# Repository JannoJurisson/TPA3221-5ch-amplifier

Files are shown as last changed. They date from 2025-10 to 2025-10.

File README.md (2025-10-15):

# TPA3221-5ch-amplifier
A D-class car amplifier based on TPA3221, replaces BOSE 294009 car amplifier PCB.

The amplifier uses a Push-pull SMPS with a SG3525 controller to boost 12V to 24V. Transformer is hand-made using non-gapped ferrite transformer core TDK E-50.
Similar E cores can be used as the transformer is fastened to the pcb using cable ties 

There a 5 channels:
Channel 1-4 -> speaker outputs (@ 4ohm speakers > ~4x60W)
Channel 5   -> subwoofer output (TPA3221 in PBTL operation, @ 4ohm woofer > ~100w)

TPA3221 5ch amp_top
TPA3221 5ch amp_bottom

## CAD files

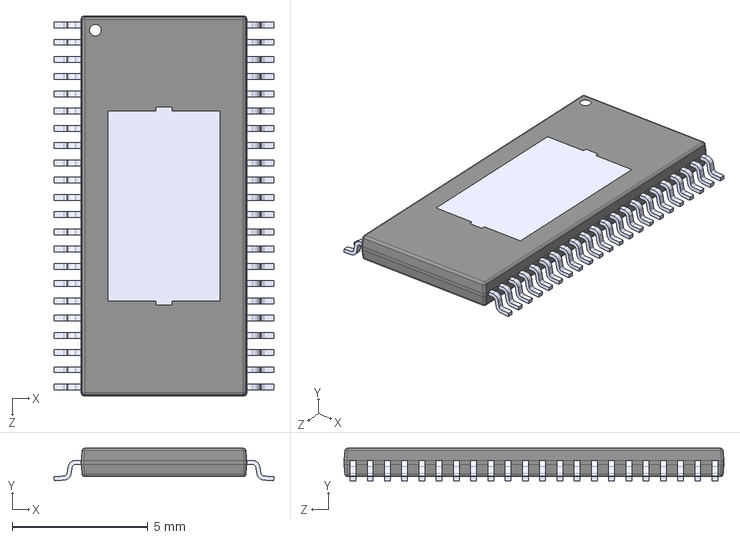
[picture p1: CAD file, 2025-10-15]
KiCAD/3d_models/TPA3221DDV.STEP
8.10 x 1.20 x 14.0 mm

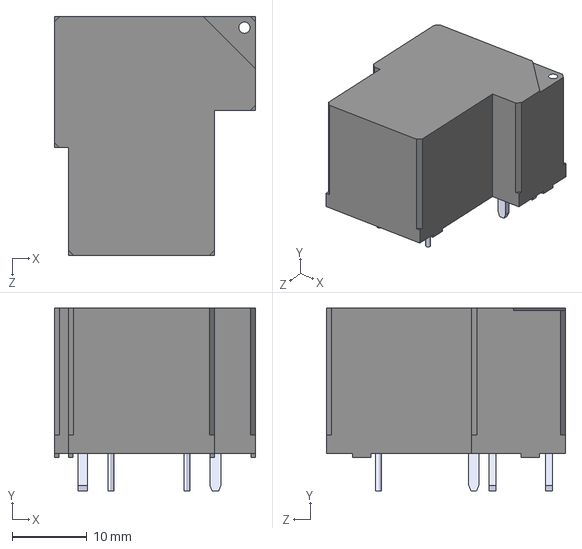
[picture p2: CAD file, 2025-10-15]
KiCAD/3d_models/GK-A-1A-12D-G.STEP
27.0 x 24.5 x 32.1 mm

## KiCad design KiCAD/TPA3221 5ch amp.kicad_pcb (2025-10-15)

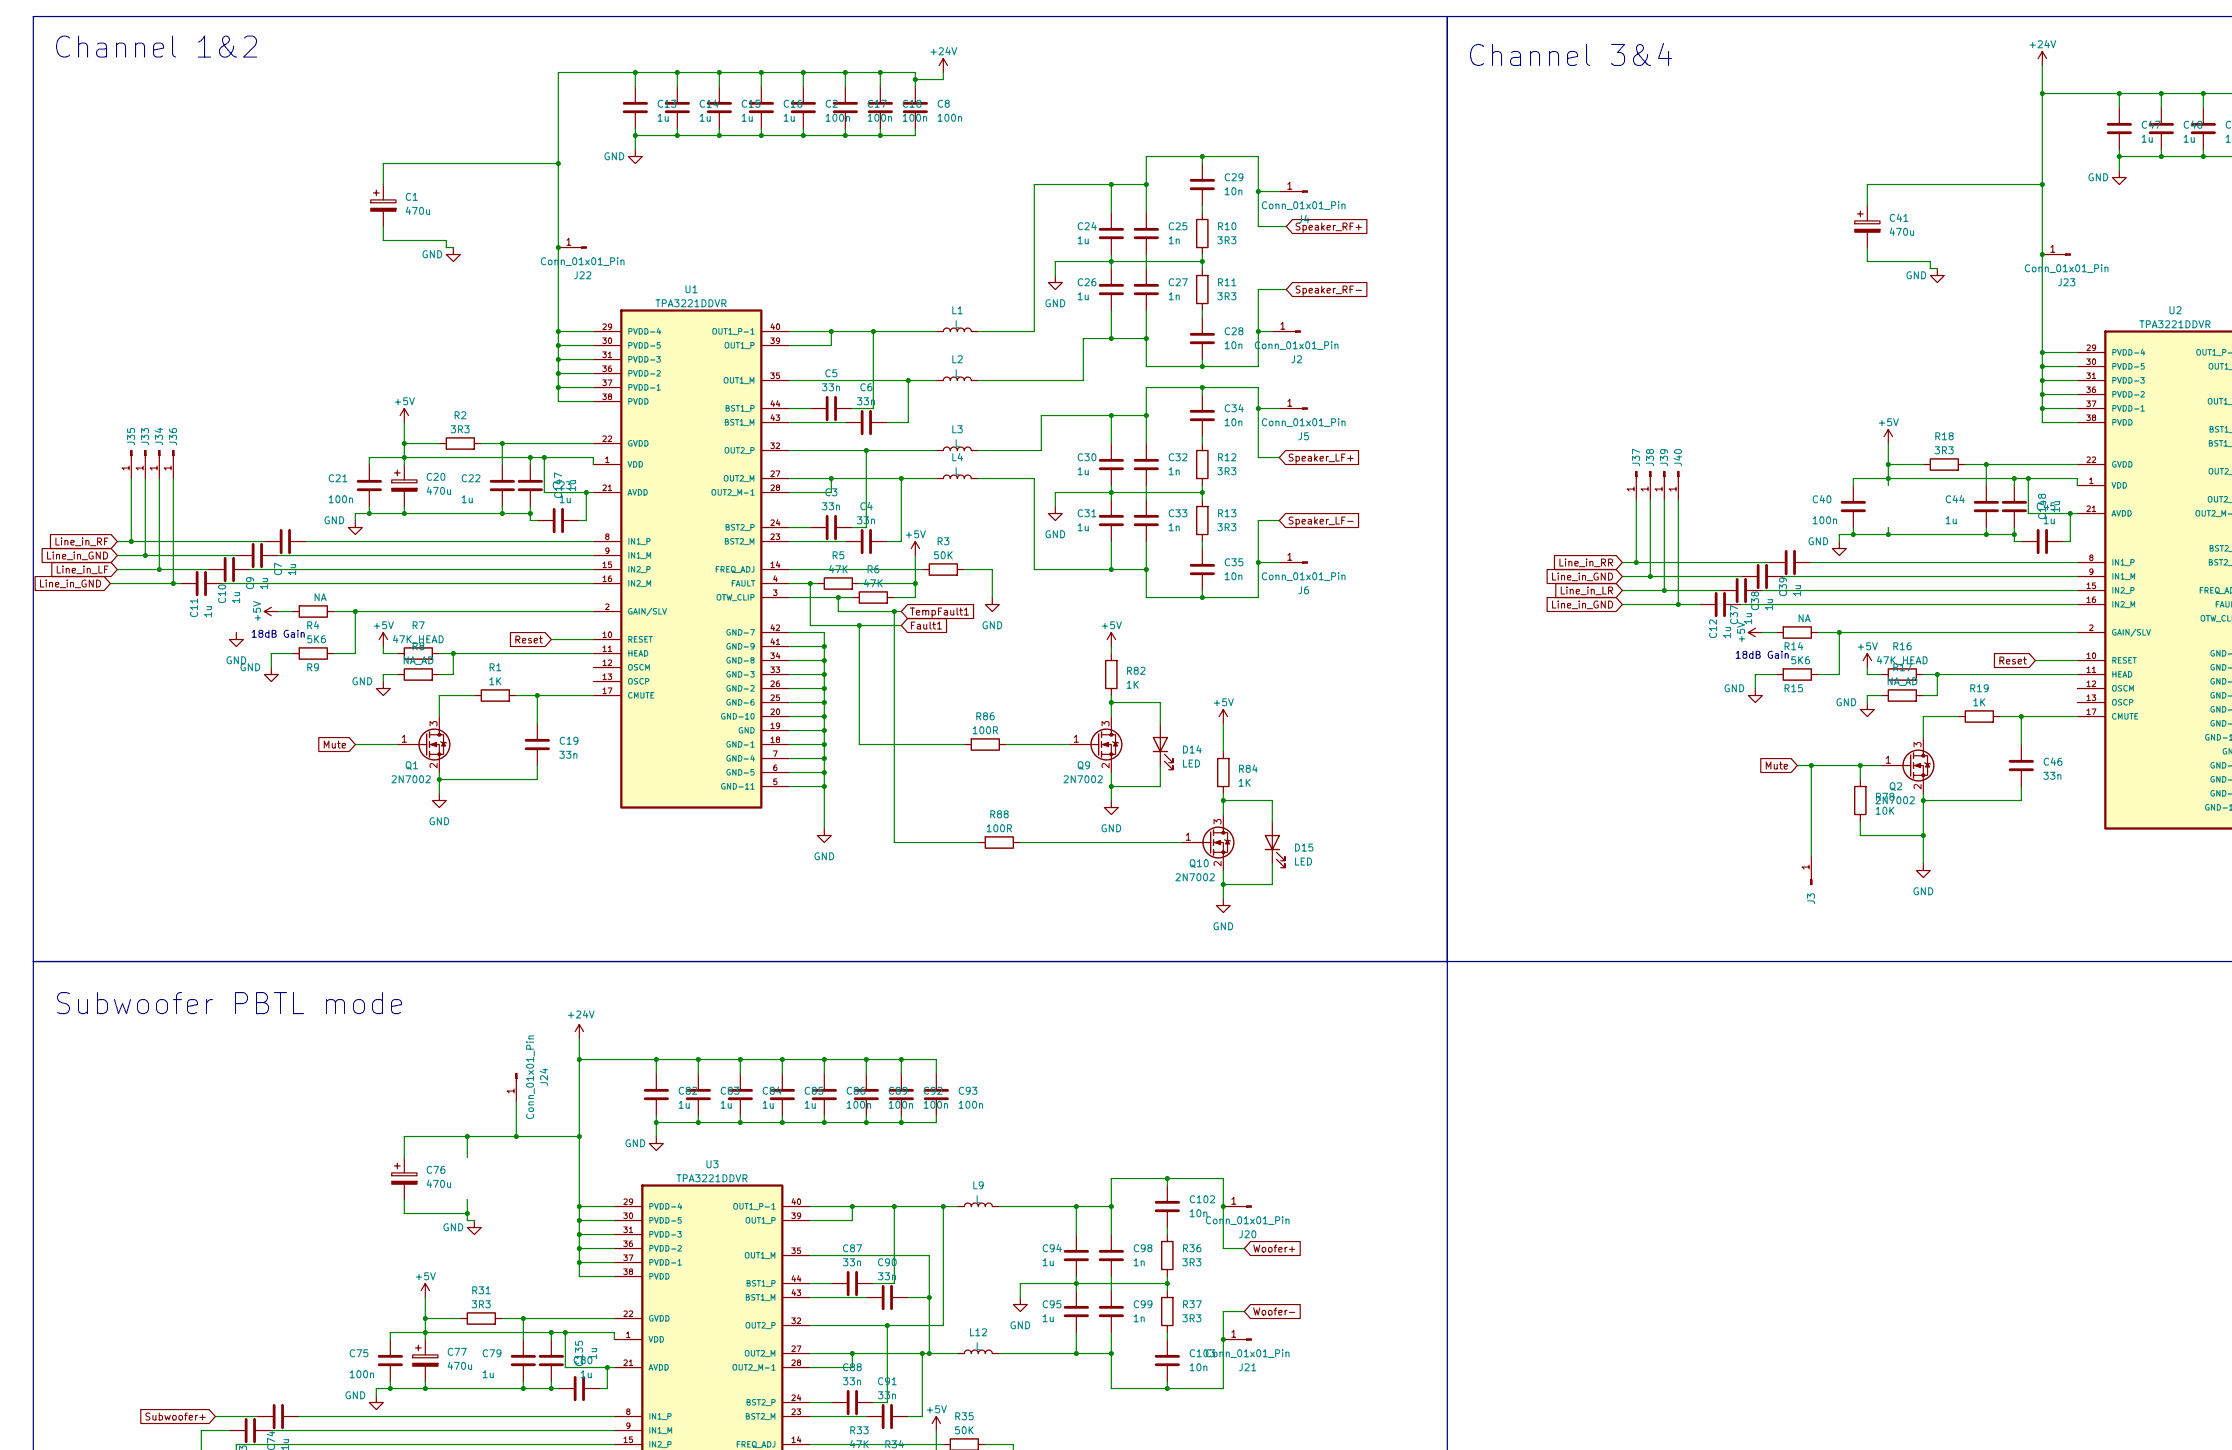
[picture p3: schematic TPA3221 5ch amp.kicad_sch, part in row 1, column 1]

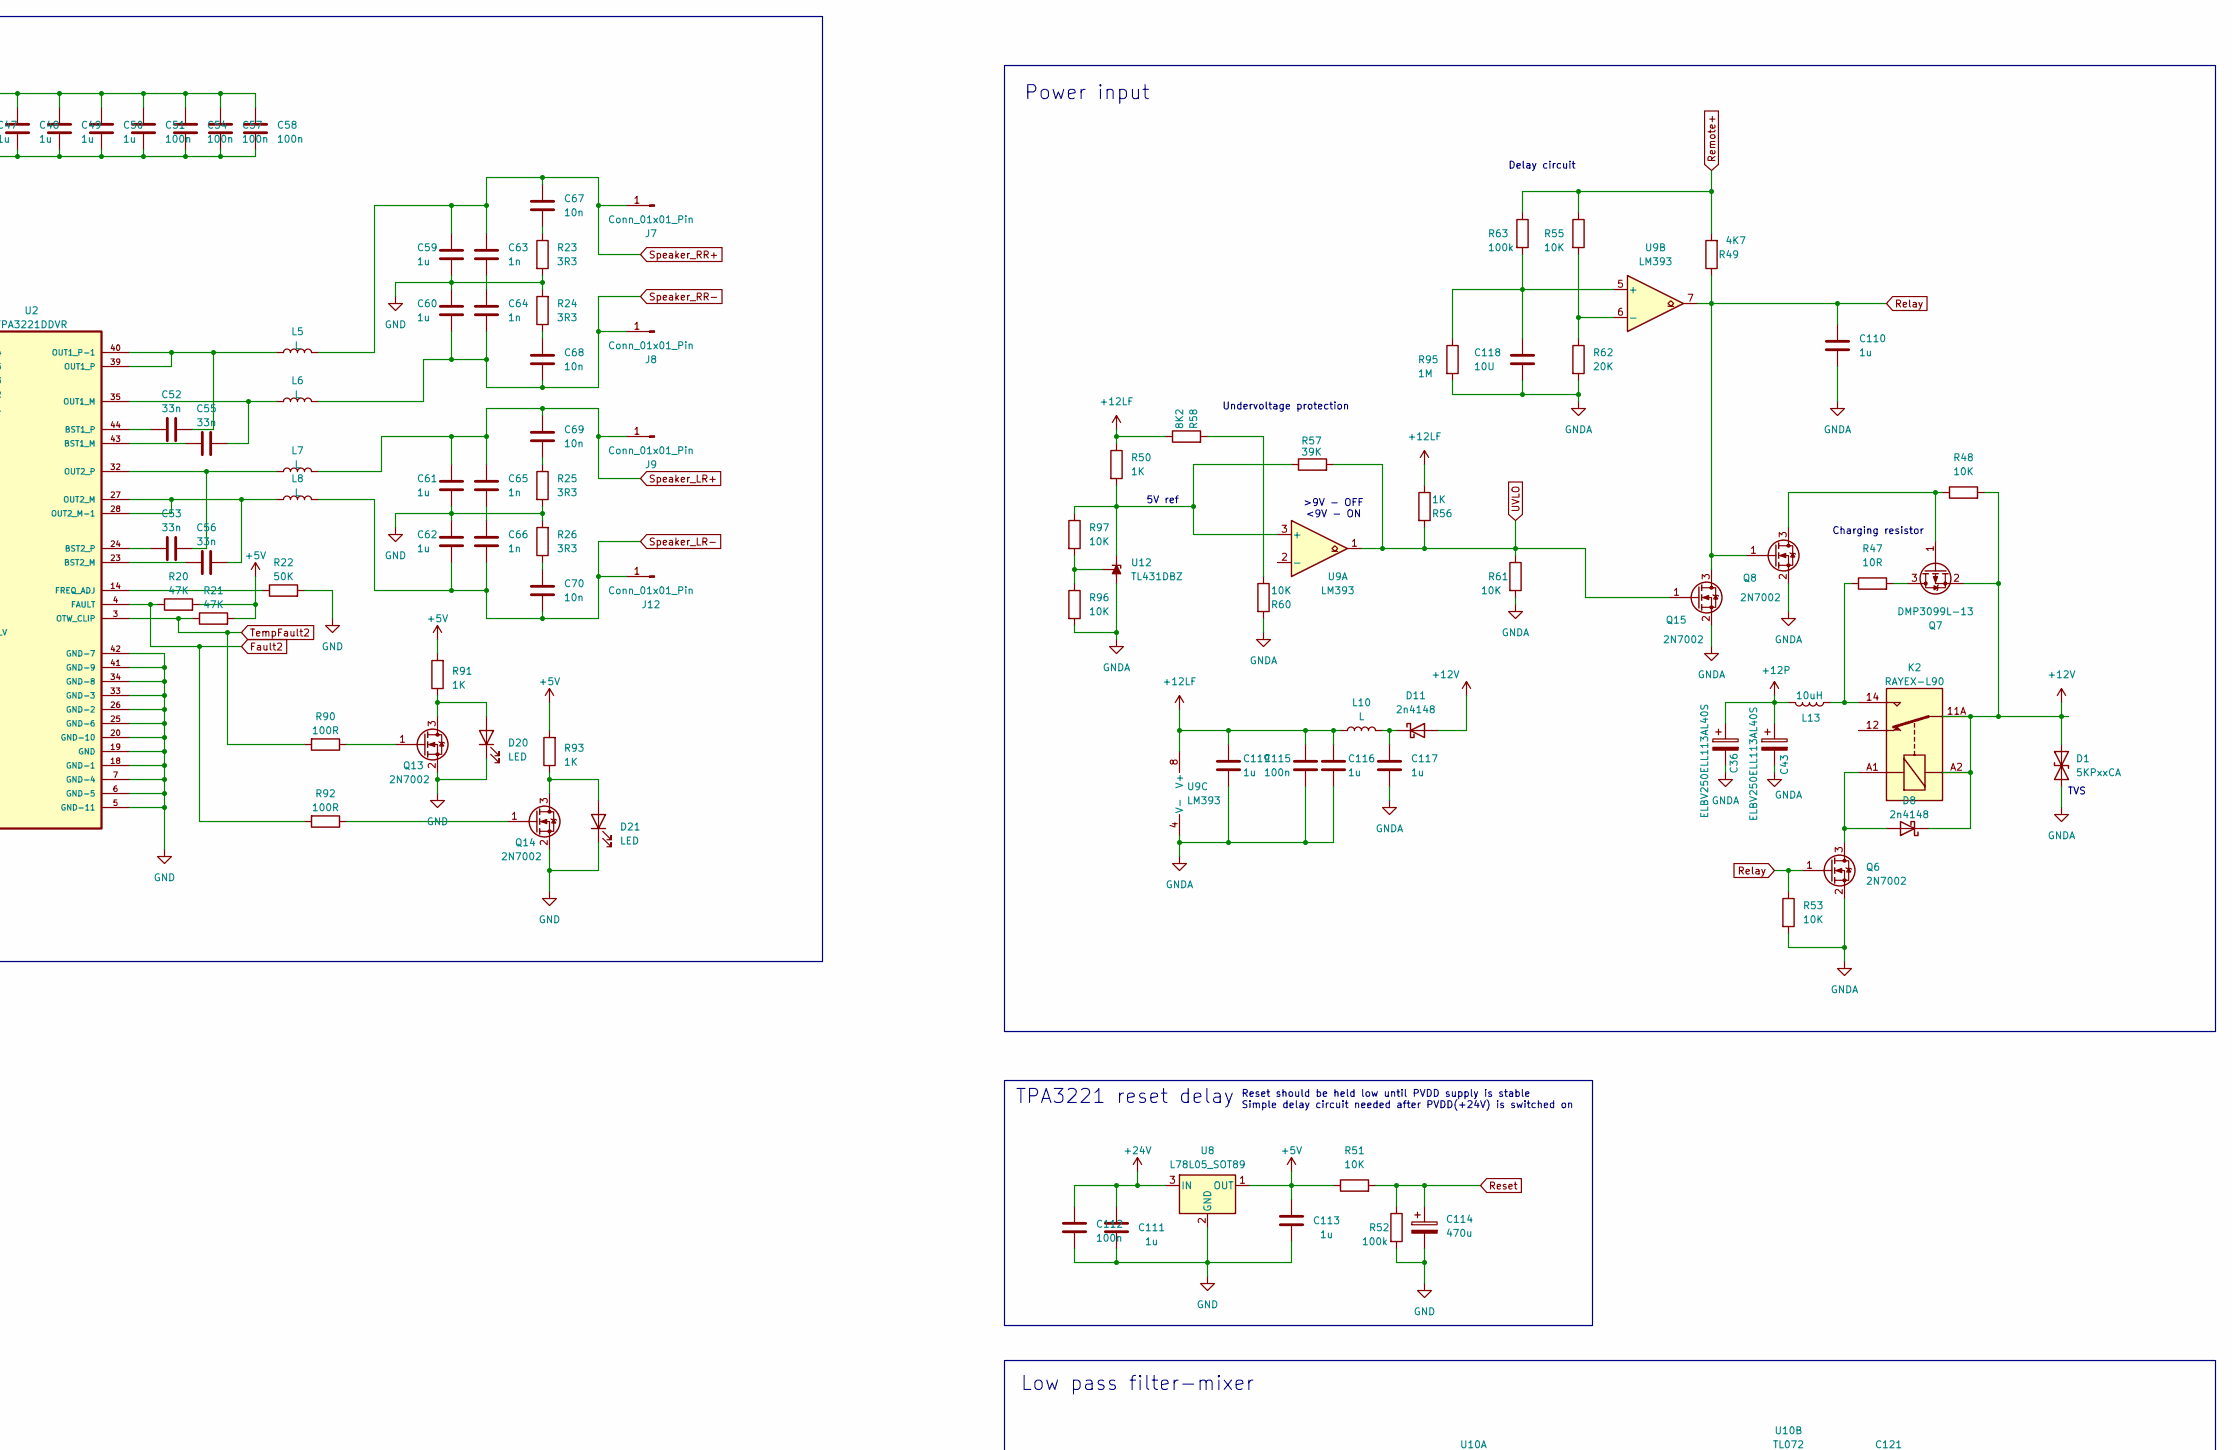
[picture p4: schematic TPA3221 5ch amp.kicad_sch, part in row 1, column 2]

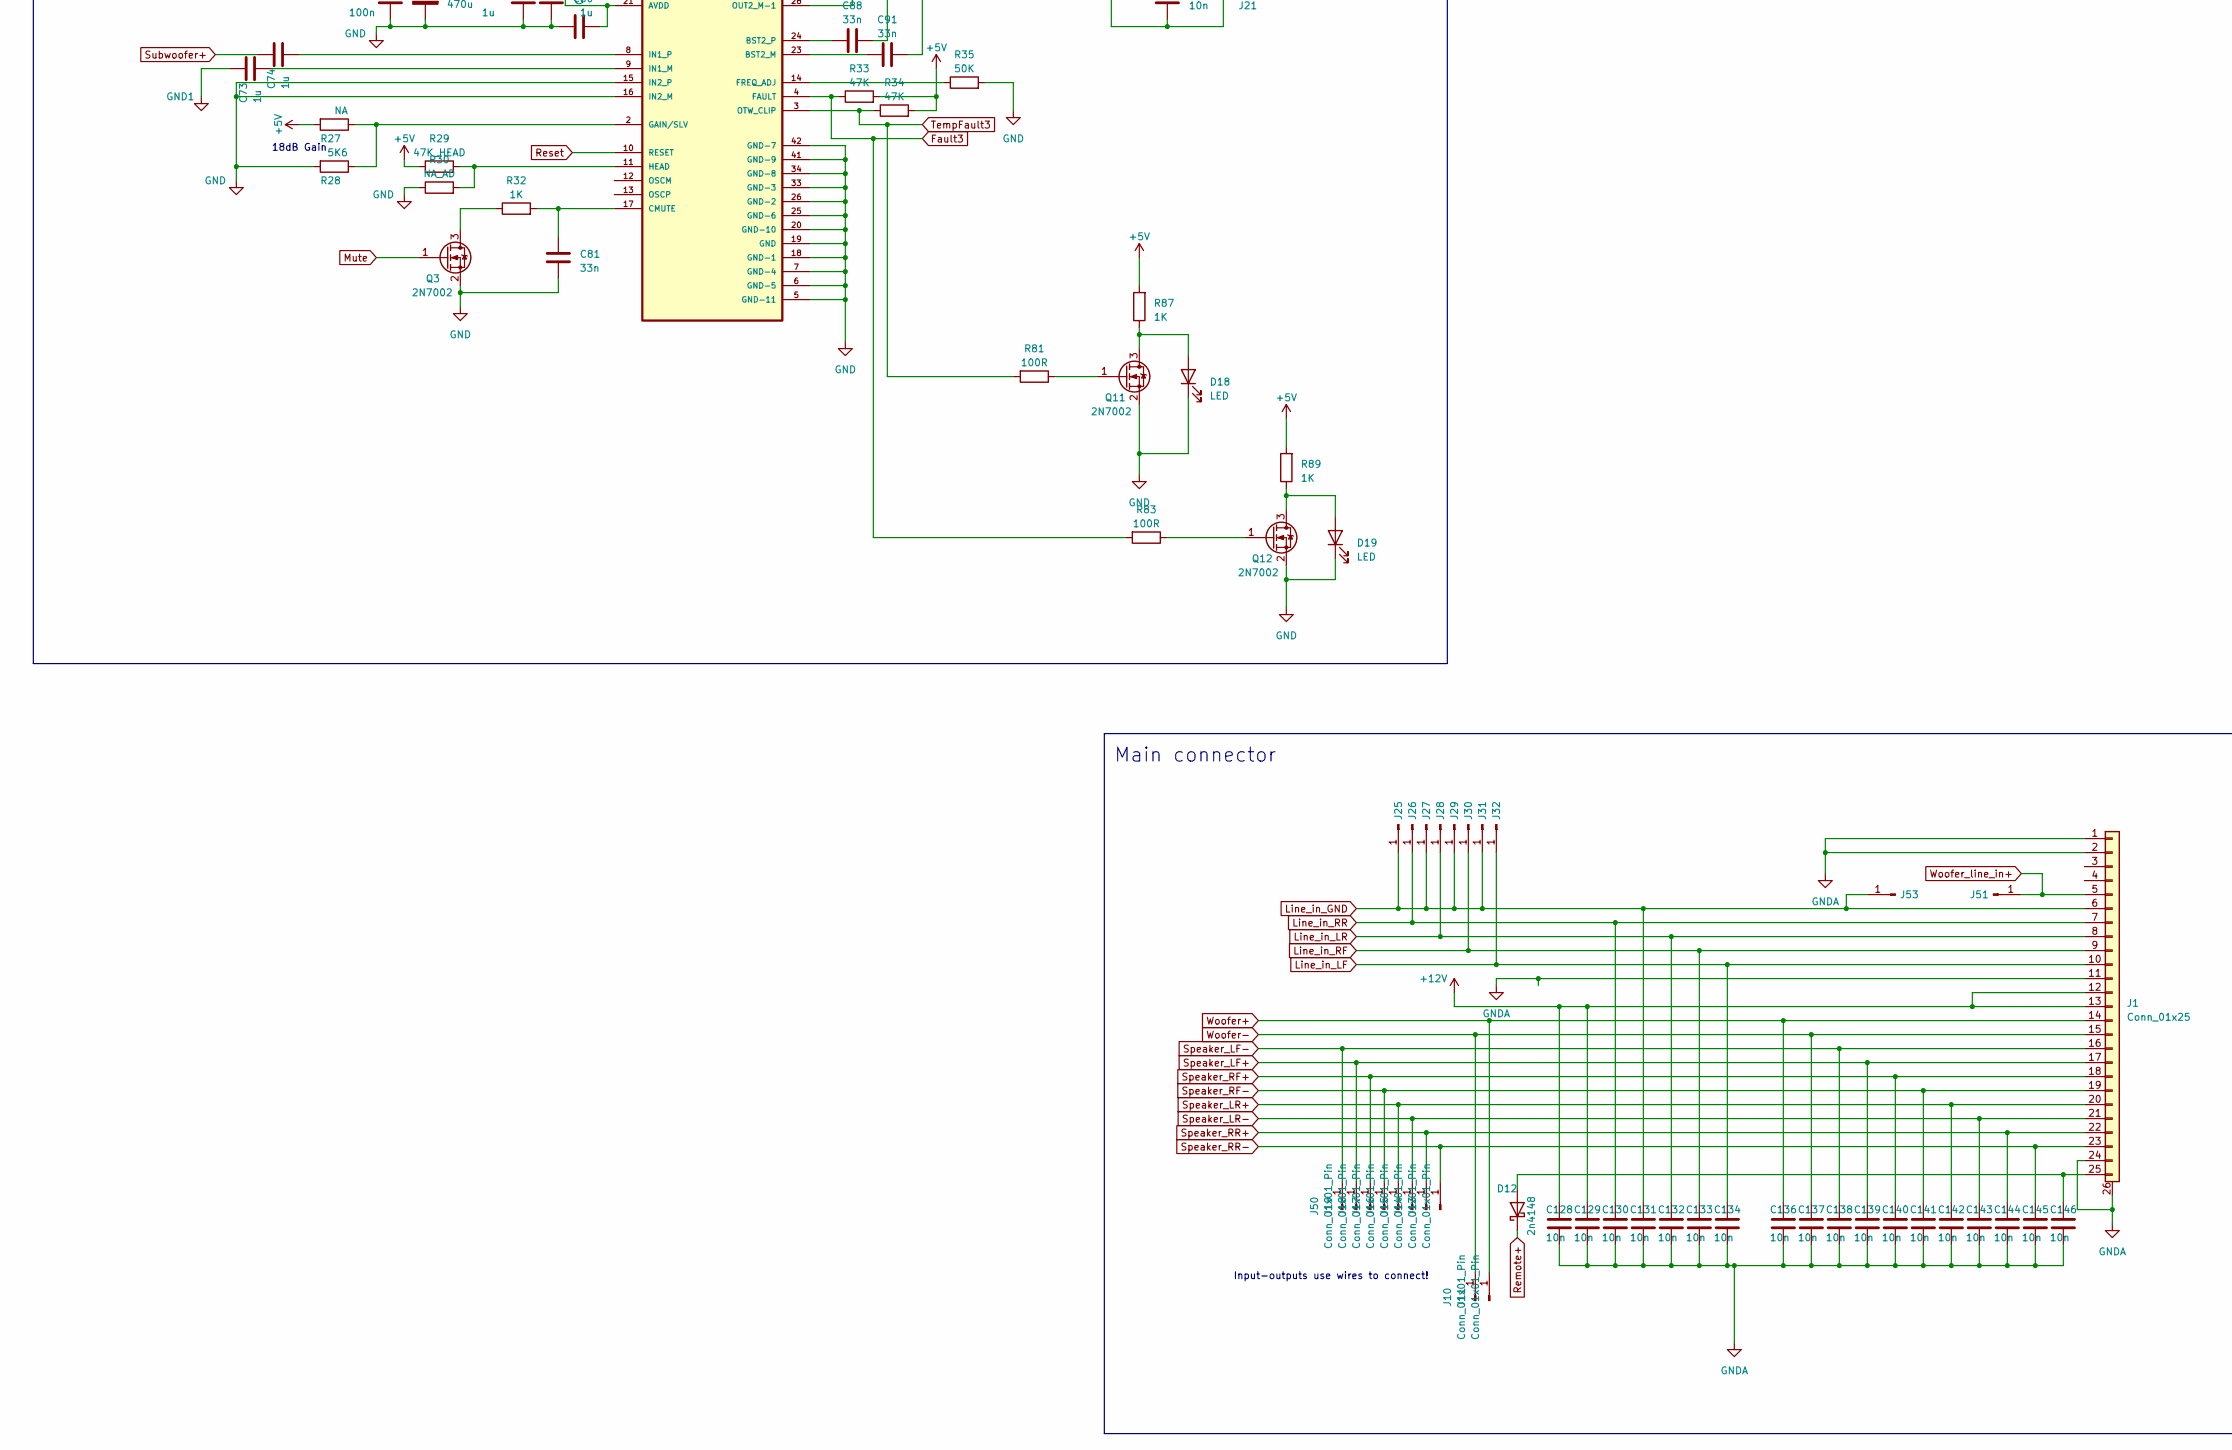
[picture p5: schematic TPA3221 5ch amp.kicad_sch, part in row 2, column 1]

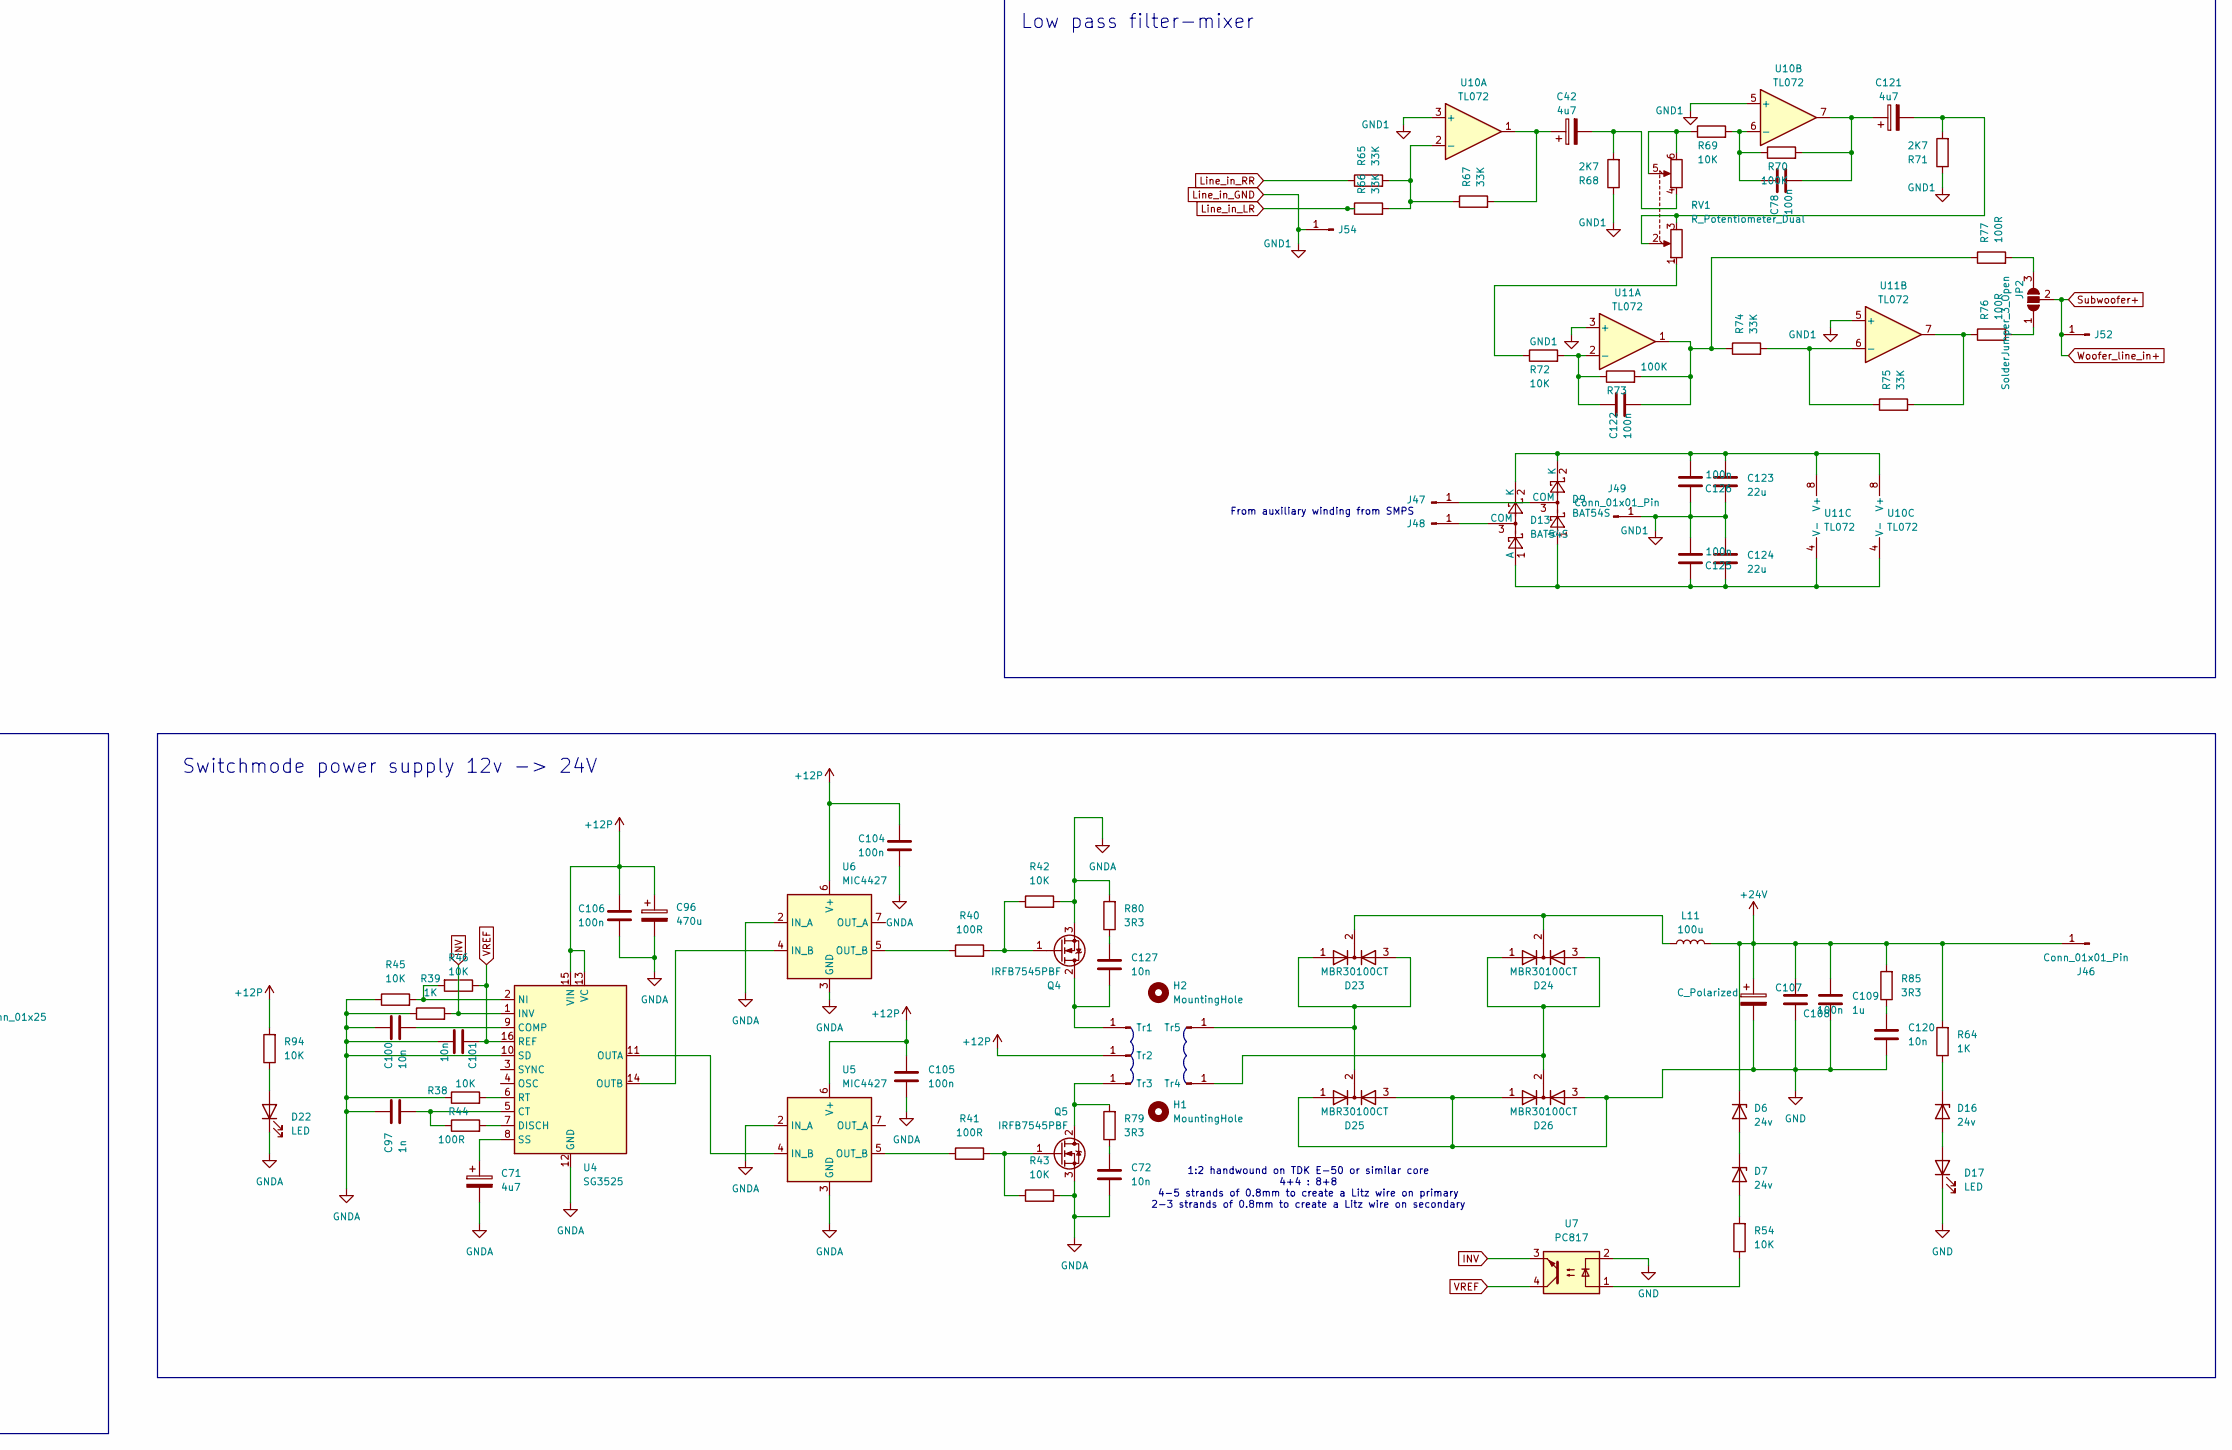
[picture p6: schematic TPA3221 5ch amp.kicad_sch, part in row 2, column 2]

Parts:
C1, C41, C76: 470u; CP_Elec_10x12.5
C2, C8, C17, C18, C21, C40, C51, C54, C57, C58, C75, C86, C89, C92, C93, C104, C105, C106, C108, C112, C115, C125, C126: 100n; C_0603_1608Metric
C3, C4, C5, C6, C19, C46, C52, C53, C55, C56, C81, C87, C88, C90, C91: 33n; C_0603_1608Metric
C7, C9, C10, C11, C12, C24, C26, C30, C31, C37, C38, C39, C59, C60, C61, C62, C73, C74, C94, C95: 1u; C_Rect_L7.2mm_W4.5mm_P5.00mm_FKS2_FKP2_MKS2_MKP2
C13, C14, C15, C16, C47, C48, C49, C50, C82, C83, C84, C85, C109, C110, C111, C113, C116, C119: 1u; C_0805_2012Metric
C20: 470u; CP_Elec_6.3x5.4_Nichicon
C22, C23, C44, C45, C79, C80, C117, C135, C147, C148: 1u; C_0603_1608Metric
C25, C27, C32, C33, C63, C64, C65, C66, C97, C98, C99: 1n; C_0603_1608Metric
C28, C29, C34, C35, C67, C68, C69, C70, C100, C101, C102, C103: 10n; C_0603_1608Metric
C36, C43: ELBV250ELL113AL40S; CP_Radial_D18.0mm_P7.50mm
C42, C71, C121: 4u7; CP_Radial_D4.0mm_P2.00mm
C72, C120, C127, C128, C129, C130, C131, C132, C133, C134, C136, C137, C138, C139, C140, C141, C142, C143, C144, C145, C146: 10n; C_0805_2012Metric
C77: 470u; CP_Elec_6.3x5.2
C78, C122: 100n; C_Rect_L7.0mm_W3.5mm_P5.00mm
C96, C114: 470u; CP_Elec_6.3x5.4
C107: C_Polarized; CP_Radial_D18.0mm_P7.50mm
C118: 10U; C_0805_2012Metric
C123, C124: 22u; C_1206_3216Metric
D1: 5KPxxCA; D_P600_R-6_P20.00mm_Horizontal
D6, D7, D16: 24v; D_MiniMELF
D8, D11, D12: 2n4148; D_MiniMELF
D9, D13: BAT54S; SOT-23
D14, D15, D17, D18, D19, D20, D21, D22: LED; LED_0603_1608Metric
D23, D24, D25, D26: MBR30100CT; TO-220-3_Horizontal_TabDown
H1, H2: MountingHole; MountingHole_3.2mm_M3
J1: Conn_01x25; AMP_connector_Audi_AMP3510
J2, J4, J5, J6, J7, J8, J9, J10, J11, J12, J13, J14, J15, J16, J17, J18, J19, J20, J21, J22, J23, J24, J46, J50: Conn_01x01_Pin; SolderWire-1.5sqmm_1x01_D1.7mm_OD3mm
J3: MUTE; TestPoint_Keystone_5015_Micro-Minature
J25, J27, J29, J31, J33, J36, J38, J40, J53, J54: -; TestPoint_Keystone_5015_Micro-Minature
J26, J37: RR; TestPoint_Keystone_5015_Micro-Minature
J28, J39: LR; TestPoint_Keystone_5015_Micro-Minature
J30, J35: RF; TestPoint_Keystone_5015_Micro-Minature
J32, J34: LF; TestPoint_Keystone_5015_Micro-Minature
J41: Tr3; SolderWire-2.5sqmm_1x01_D2.4mm_OD4.4mm
J42: Tr2; SolderWire-2.5sqmm_1x01_D2.4mm_OD4.4mm
J43: Tr1; SolderWire-2.5sqmm_1x01_D2.4mm_OD4.4mm
J44: Tr5; SolderWire-2.5sqmm_1x01_D2.4mm_OD4.4mm
J45: Tr4; SolderWire-2.5sqmm_1x01_D2.4mm_OD4.4mm
J47, J48, J49: Conn_01x01_Pin; SolderWire-0.75sqmm_1x01_D1.25mm_OD2.3mm
J51: Woofer_in; TestPoint_Keystone_5015_Micro-Minature
J52: W_in; TestPoint_Keystone_5015_Micro-Minature
JP2: SolderJumper_3_Open; SolderJumper-3_P1.3mm_Open_RoundedPad1.0x1.5mm
K2: RAYEX-L90; Relay_SPDT_RAYEX-L90
L1, L2, L3, L4, L5, L6, L7, L8, L9, L12: L; L_Bourns_SRR1210A
L10: L; L_1210_3225Metric
L11: 100u; L_Radial_D16.8mm_P11.43mm_Vishay_IHB-1
L13: 10uH; L_Toroid_Horizontal_D32.5mm_P30.00mm_Bourns_2300
Q1, Q2, Q3, Q6, Q8, Q9, Q10, Q11, Q12, Q13, Q14, Q15: 2N7002; SOT-23
Q4, Q5: IRFB7545PBF; TO-220-3_Horizontal_TabDown
Q7: DMP3099L-13; SOT-23
R1, R19, R32, R39, R50, R56, R64, R82, R84, R87, R89, R91, R93: 1K; R_0603_1608Metric
R2, R10, R11, R12, R13, R18, R23, R24, R25, R26, R31, R36, R37, R79, R80, R85: 3R3; R_0805_2012Metric
R3, R22, R35: 50K; R_0805_2012Metric
R4, R14, R27: NA; R_0805_2012Metric
R5, R6, R20, R21, R33, R34: 47K; R_0603_1608Metric
R7, R16, R29: 47K_HEAD; R_0603_1608Metric
R8, R17, R30: NA_AD; R_0603_1608Metric
R9, R15, R28: 5K6; R_0805_2012Metric
R38, R42, R43, R45, R46, R48, R51, R53, R54, R55, R60, R61, R69, R72, R78, R94, R96, R97: 10K; R_0603_1608Metric
R40, R41: 100R; R_0805_2012Metric
R44, R76, R77, R81, R83, R86, R88, R90, R92: 100R; R_0603_1608Metric
R47: 10R; R_1210_3225Metric
R49: 4K7; R_0603_1608Metric
R52, R63: 100k; R_0603_1608Metric
R57: 39K; R_0603_1608Metric
R58: 8K2; R_0603_1608Metric
R62: 20K; R_0603_1608Metric
R65, R66, R67, R74, R75: 33K; R_0603_1608Metric
R68, R71: 2K7; R_0603_1608Metric
R70, R73: 100K; R_0603_1608Metric
R95: 1M; R_0603_1608Metric
RV1: R_Potentiometer_Dual; Potentiometer_Alpha_RD902F-40-00D_Dual_Vertical_CircularHol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
U1, U2, U3: TPA3221DDVR; SOP63P810X120-44N
U4: SG3525; SOIC-16_3.9x9.9mm_P1.27mm
U5, U6: MIC4427; SOIC-8_3.9x4.9mm_P1.27mm
U7: PC817; DIP-4_W7.62mm
U8: L78L05_SOT89; SOT-89-3
U9: LM393; SOIC-8_3.9x4.9mm_P1.27mm
U10, U11: TL072; SOIC-8_3.9x4.9mm_P1.27mm
U12: TL431DBZ; SOT-23

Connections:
+5V: C20.1, C21.1, C23.1, C40.1, C45.1, C75.1, C77.1, C80.1, C113.1, C135.2, C147.2, C148.2, R2.1, R4.2, R5.2, R6.2, R7.1, R14.2, R16.1, R18.1, R20.2, R21.2, R27.2, R29.1, R31.1, R33.2, R34.2, R51.1, R82.2, R84.2, R87.2, R89.2, R91.2, R93.2, U1.1 (VDD), U1.21 (AVDD), U2.1 (VDD), U2.21 (AVDD), U3.1 (VDD), U3.21 (AVDD), U8.1 (OUT)
+12LF: C115.1, C116.1, C119.1, L10.1, R50.1, R56.1, R58.1, U9.8 (V+)
+12P: C36.1, C43.1, C96.1, C104.1, C105.1, C106.1, J42.1, L13.2, R94.2, U4.13 (VC), U4.15 (VIN), U5.6 (V+), U6.6 (V+)
+12V: C128.2, C129.2, D1.1 (A1), D8.1 (K), D11.2 (A), J1.12, J1.13, K2.11A, K2.11B, K2.A2, Q7.2 (S), R48.2
+24V: C1.1, C2.1, C8.1, C13.1, C14.1, C15.1, C16.1, C17.1, C18.1, C41.1, C47.1, C48.1, C49.1, C50.1, C51.1, C54.1, C57.1, C58.1, C76.1, C82.1, C83.1, C84.1, C85.1, C86.1, C89.1, C92.1, C93.1, C107.1, C108.1, C109.1, C111.1, C112.1, D6.1 (K), J22.1, J23.1, J24.1, J46.1, L11.2, R64.2, R85.2, U1.29 (PVDD-4), U1.30 (PVDD-5), U1.31 (PVDD-3), U1.36 (PVDD-2), U1.37 (PVDD-1), U1.38 (PVDD), U2.29 (PVDD-4), U2.30 (PVDD-5), U2.31 (PVDD-3), U2.36 (PVDD-2), U2.37 (PVDD-1), U2.38 (PVDD), U3.29 (PVDD-4), U3.30 (PVDD-5), U3.31 (PVDD-3), U3.36 (PVDD-2), U3.37 (PVDD-1), U3.38 (PVDD), U8.3 (IN)
Fault1: R5.1, R86.2, U1.4 (FAULT)
Fault2: R20.1, R92.2, U2.4 (FAULT)
Fault3: R33.1, R83.2, U3.4 (FAULT)
GND: C1.2, C2.2, C8.2, C13.2, C14.2, C15.2, C16.2, C17.2, C18.2, C19.1, C20.2, C21.2, C22.2, C23.2, C24.1, C26.2, C30.1, C31.2, C40.2, C41.2, C44.2, C45.2, C46.1, C47.2, C48.2, C49.2, C50.2, C51.2, C54.2, C57.2, C58.2, C59.1, C60.2, C61.1, C62.2, C75.2, C76.2, C77.2, C79.2, C80.2, C81.1, C82.2, C83.2, C84.2, C85.2, C86.2, C89.2, C92.2, C93.2, C94.1, C95.2, C107.2, C108.2, C109.2, C111.2, C112.2, C113.2, C114.2, C120.1, C135.1, C147.1, C148.1, D14.1 (K), D15.1 (K), D17.1 (K), D18.1 (K), D19.1 (K), D20.1 (K), D21.1 (K), D25.1 (A), D25.3 (A), D26.1 (A), D26.3 (A), Q1.2 (S), Q2.2 (S), Q3.2 (S), Q9.2 (S), Q10.2 (S), Q11.2 (S), Q12.2 (S), Q13.2 (S), Q14.2 (S), R3.2, R8.1, R9.2, R10.2, R11.2, R12.2, R13.2, R15.2, R17.1, R22.2, R23.2, R24.2, R25.2, R26.2, R28.2, R30.1, R35.2, R36.2, R37.2, R52.2, R78.1, U1.5 (GND-11), U1.6 (GND-5), U1.7 (GND-4), U1.18 (GND-1), U1.19 (GND), U1.20 (GND-10), U1.25 (GND-6), U1.26 (GND-2), U1.33 (GND-3), U1.34 (GND-8), U1.41 (GND-9), U1.42 (GND-7), U2.5 (GND-11), U2.6 (GND-5), U2.7 (GND-4), U2.18 (GND-1), U2.19 (GND), U2.20 (GND-10), U2.25 (GND-6), U2.26 (GND-2), U2.33 (GND-3), U2.34 (GND-8), U2.41 (GND-9), U2.42 (GND-7), U3.5 (GND-11), U3.6 (GND-5), U3.7 (GND-4), U3.15 (IN2_P), U3.16 (IN2_M), U3.18 (GND-1), U3.19 (GND), U3.20 (GND-10), U3.25 (GND-6), U3.26 (GND-2), U3.33 (GND-3), U3.34 (GND-8), U3.41 (GND-9), U3.42 (GND-7), U7.2, U8.2 (GND)
GNDA: C36.2, C43.2, C71.2, C72.1, C96.2, C97.1, C100.1, C101.1, C104.2, C105.2, C106.2, C110.2, C115.2, C116.2, C117.2, C118.2, C119.2, C128.1, C129.1, C130.1, C131.1, C132.1, C133.1, C134.1, C136.1, C137.1, C138.1, C139.1, C140.1, C141.1, C142.1, C143.1, C144.1, C145.1, C146.1, D1.2 (A2), D22.1 (K), J1.1, J1.2, J1.11, J1.24, J1.26 (gnd), Q4.3 (S), Q5.3 (S), Q6.2 (S), Q8.2 (S), Q15.2 (S), R38.1, R39.1, R42.2, R43.2, R45.1, R53.2, R60.2, R61.2, R62.2, R80.2, R95.2, R96.2, U4.10 (SD), U4.12 (GND), U5.2 (IN_A), U5.3 (GND), U6.2 (IN_A), U6.3 (GND), U9.4 (V-), U12.3 (A)
INV: R39.2, U4.1 (INV), U7.3
Line_in_GND: C9.2, C11.2, C12.2, C38.2, C73.2, C123.2, C124.1, C125.2, C126.1, C131.2, J1.6, J25.1, J27.1, J29.1, J31.1, J33.1, J36.1, J38.1, J40.1, J49.1, J53.1, J54.1, R68.1, R71.1, U10.3 (+), U10.5 (+), U11.3 (+), U11.5 (+)
Line_in_LF: C10.2, C134.2, J1.10, J32.1, J34.1
Line_in_LR: C37.2, C132.2, J1.8, J28.1, J39.1, R66.1
Line_in_RF: C7.2, C133.2, J1.9, J30.1, J35.1
Line_in_RR: C39.2, C130.2, J1.7, J26.1, J37.1, R65.1
Mute: J3.1, Q1.1 (G), Q2.1 (G), Q3.1 (G), R78.2
unnamed: C25.1, C27.2
unnamed: C28.2, R11.1
unnamed: C29.1, R10.1
unnamed: C32.1, C33.2
unnamed: C34.1, R12.1
unnamed: C35.2, R13.1
unnamed: C42.1, R67.2, U10.1
unnamed: C42.2, R68.2, RV1.4
unnamed: C63.1, C64.2
unnamed: C65.1, C66.2
unnamed: C67.1, R23.1
unnamed: C68.2, R24.1
unnamed: C69.1, R25.1
unnamed: C70.2, R26.1
unnamed: C72.2, R79.1
unnamed: C98.1, C99.2
unnamed: C102.1, R36.1
unnamed: C103.2, R37.1
unnamed: C120.2, R85.1
unnamed: C78.1, C121.1, R70.2, U10.7
unnamed: C121.2, R71.2, RV1.2, RV1.3
unnamed: C122.1, R73.2, R74.1, R77.1, U11.1
unnamed: C127.2, R80.1
unnamed: D6.2 (A), D7.1 (K)
unnamed: D7.2 (A), R54.2
unnamed: D8.2 (A), K2.A1, Q6.3 (D)
unnamed: D9.3 (COM), J47.1
unnamed: C117.1, D11.1 (K), L10.2
unnamed: C146.2, D12.2 (A), J1.25
unnamed: C124.2, C125.1, D9.1 (A), D13.1 (A), U10.4 (V-), U11.4 (V-)
unnamed: D13.3 (COM), J48.1
unnamed: C123.1, C126.2, D9.2 (K), D13.2 (K), U10.8 (V+), U11.8 (V+)
unnamed: D14.2 (A), Q9.3 (D), R82.1
unnamed: D15.2 (A), Q10.3 (D), R84.1
unnamed: D16.2 (A), D17.2 (A)
unnamed: D16.1 (K), R64.1
unnamed: D18.2 (A), Q11.3 (D), R87.1
unnamed: D19.2 (A), Q12.3 (D), R89.1
unnamed: D20.2 (A), Q13.3 (D), R91.1
unnamed: D21.2 (A), Q14.3 (D), R93.1
unnamed: D22.2 (A), R94.1
unnamed: D23.2 (K), D24.2 (K), L11.1
unnamed: D23.1 (A), D23.3 (A), D25.2 (K), J44.1
unnamed: D24.1 (A), D24.3 (A), D26.2 (K), J45.1
unnamed: J41.1, Q5.2 (D), R79.2
unnamed: C127.1, J43.1, Q4.2 (D)
unnamed: JP2.1 (A), R76.2
unnamed: JP2.3 (B), R77.2
unnamed: K2.14, L13.1, R47.1
unnamed: Q1.3 (D), R1.1
unnamed: Q2.3 (D), R19.1
unnamed: Q3.3 (D), R32.1
unnamed: Q4.1 (G), R40.2, R42.1
unnamed: Q5.1 (G), R41.2, R43.1
unnamed: Q7.3 (D), R47.2
unnamed: Q7.1 (G), Q8.3 (D), R48.1
unnamed: Q9.1 (G), R86.1
unnamed: Q10.1 (G), R88.1
unnamed: Q11.1 (G), R81.1
unnamed: Q12.1 (G), R83.1
unnamed: Q13.1 (G), R90.1
unnamed: Q14.1 (G), R92.1
unnamed: R54.1, U7.1
unnamed: R58.2, R60.1
unnamed: R69.1, RV1.5, RV1.6
unnamed: R72.1, RV1.1
unnamed: R75.2, R76.1, U11.7
unnamed: C6.1, U1.43 (BST1_M)
unnamed: C5.1, U1.44 (BST1_P)
unnamed: C4.1, U1.23 (BST2_M)
unnamed: C3.1, U1.24 (BST2_P)
unnamed: C19.2, R1.2, U1.17 (CMUTE)
unnamed: R3.1, U1.14 (FREQ_ADJ)
unnamed: R4.1, R9.1, U1.2 (GAIN/SLV)
unnamed: C22.1, R2.2, U1.22 (GVDD)
unnamed: R7.2, R8.2, U1.11 (HEAD)
unnamed: C9.1, U1.9 (IN1_M)
unnamed: C7.1, U1.8 (IN1_P)
unnamed: C11.1, U1.16 (IN2_M)
unnamed: C10.1, U1.15 (IN2_P)
unnamed: C6.2, L2.1, U1.35 (OUT1_M)
unnamed: C5.2, L1.1, U1.39 (OUT1_P), U1.40 (OUT1_P-1)
unnamed: C4.2, L4.1, U1.27 (OUT2_M), U1.28 (OUT2_M-1)
unnamed: C3.2, L3.1, U1.32 (OUT2_P)
unnamed: C55.1, U2.43 (BST1_M)
unnamed: C52.1, U2.44 (BST1_P)
unnamed: C56.1, U2.23 (BST2_M)
unnamed: C53.1, U2.24 (BST2_P)
unnamed: C46.2, R19.2, U2.17 (CMUTE)
unnamed: R22.1, U2.14 (FREQ_ADJ)
unnamed: R14.1, R15.1, U2.2 (GAIN/SLV)
unnamed: C44.1, R18.2, U2.22 (GVDD)
unnamed: R16.2, R17.2, U2.11 (HEAD)
unnamed: C38.1, U2.9 (IN1_M)
unnamed: C39.1, U2.8 (IN1_P)
unnamed: C12.1, U2.16 (IN2_M)
unnamed: C37.1, U2.15 (IN2_P)
unnamed: C55.2, L6.1, U2.35 (OUT1_M)
unnamed: C52.2, L5.1, U2.39 (OUT1_P), U2.40 (OUT1_P-1)
unnamed: C56.2, L8.1, U2.27 (OUT2_M), U2.28 (OUT2_M-1)
unnamed: C53.2, L7.1, U2.32 (OUT2_P)
unnamed: C90.1, U3.43 (BST1_M)
unnamed: C87.1, U3.44 (BST1_P)
unnamed: C91.1, U3.23 (BST2_M)
unnamed: C88.1, U3.24 (BST2_P)
unnamed: C81.2, R32.2, U3.17 (CMUTE)
unnamed: R35.1, U3.14 (FREQ_ADJ)
unnamed: R27.1, R28.1, U3.2 (GAIN/SLV)
unnamed: C79.1, R31.2, U3.22 (GVDD)
unnamed: R29.2, R30.2, U3.11 (HEAD)
unnamed: C73.1, U3.9 (IN1_M)
unnamed: C74.1, U3.8 (IN1_P)
unnamed: C90.2, C91.2, L12.1, U3.27 (OUT2_M), U3.28 (OUT2_M-1), U3.35 (OUT1_M)
unnamed: C87.2, C88.2, L9.1, U3.32 (OUT2_P), U3.39 (OUT1_P), U3.40 (OUT1_P-1)
unnamed: C100.2, U4.9 (COMP)
unnamed: C97.2, R44.1, U4.5 (CT)
unnamed: R44.2, U4.7 (DISCH)
unnamed: R45.2, R46.2, U4.2 (NI)
unnamed: U4.11 (OUTA), U5.4 (IN_B)
unnamed: U4.14 (OUTB), U6.4 (IN_B)
unnamed: R38.2, U4.6 (RT)
unnamed: C71.1, U4.8 (SS)
unnamed: R41.1, U5.5 (OUT_B)
unnamed: R40.1, U6.5 (OUT_B)
unnamed: C118.1, R63.2, R95.1, U9.5 (+)
unnamed: R55.2, R62.1, U9.6 (-)
unnamed: R65.2, R66.2, R67.1, U10.2 (-)
unnamed: C78.2, R69.2, R70.1, U10.6 (-)
unnamed: C122.2, R72.2, R73.1, U11.2 (-)
unnamed: R74.2, R75.1, U11.6 (-)
unnamed: R50.2, R57.1, R97.1, U9.3 (+), U12.1 (K)
unnamed: R96.1, R97.2, U12.2 (REF)
Relay: C110.1, Q6.1 (G), Q8.1 (G), Q15.3 (D), R49.1, R53.1, U9.7
Remote+: D12.1 (K), R49.2, R55.1, R63.1
Reset: C114.1, R51.2, R52.1, U1.10 (RESET), U2.10 (RESET), U3.10 (RESET)
Speaker_LF+: C30.2, C32.2, C34.2, C139.2, J1.17, J5.1, J19.1, L3.2
Speaker_LF-: C31.1, C33.1, C35.1, C138.2, J1.16, J6.1, J50.1, L4.2
Speaker_LR+: C61.2, C65.2, C69.2, C142.2, J1.20, J9.1, J16.1, L7.2
Speaker_LR-: C62.1, C66.1, C70.1, C143.2, J1.21, J12.1, J15.1, L8.2
Speaker_RF+: C24.2, C25.2, C29.2, C140.2, J1.18, J4.1, J18.1, L1.2
Speaker_RF-: C26.1, C27.1, C28.1, C141.2, J1.19, J2.1, J17.1, L2.2
Speaker_RR+: C59.2, C63.2, C67.2, C144.2, J1.22, J7.1, J14.1, L5.2
Speaker_RR-: C60.1, C64.1, C68.1, C145.2, J1.23, J8.1, J13.1, L6.2
Subwoofer+: C74.2, J1.5, J51.1, J52.1, JP2.2 (C)
TempFault1: R6.1, R88.2, U1.3 (OTW_CLIP)
TempFault2: R21.1, R90.2, U2.3 (OTW_CLIP)
TempFault3: R34.1, R81.2, U3.3 (OTW_CLIP)
UVLO: Q15.1 (G), R56.2, R57.2, R61.1, U9.1
VREF: C101.2, R46.1, U4.16 (REF), U7.4
Woofer+: C94.2, C98.2, C102.2, C136.2, J1.14, J11.1, J20.1, L9.2
Woofer-: C95.1, C99.1, C103.1, C137.2, J1.15, J10.1, J21.1, L12.2

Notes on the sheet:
TVS
Undervoltage protection
Charging resistor
Channel 1&2
5V ref
Switchmode power supply 12v -> 24V
Input-outputs use wires to connect!
Low pass filter-mixer
18dB Gain
>9V - OFF <9V - ON
TPA3221 reset delay
Subwoofer PBTL mode
Delay circuit
Reset should be held low until PVDD supply is stable Simple delay circuit needed after PVDD(+24V) is switched on
Power input
Main connector
From auxiliary winding from SMPS
Channel 3&4
1:2 handwound on TDK E-50 or similar core 4+4 : 8+8 4-5 strands of 0.8mm to create a Litz wire on primary 2-3 strands of 0.8mm to create a Litz wire on secondary

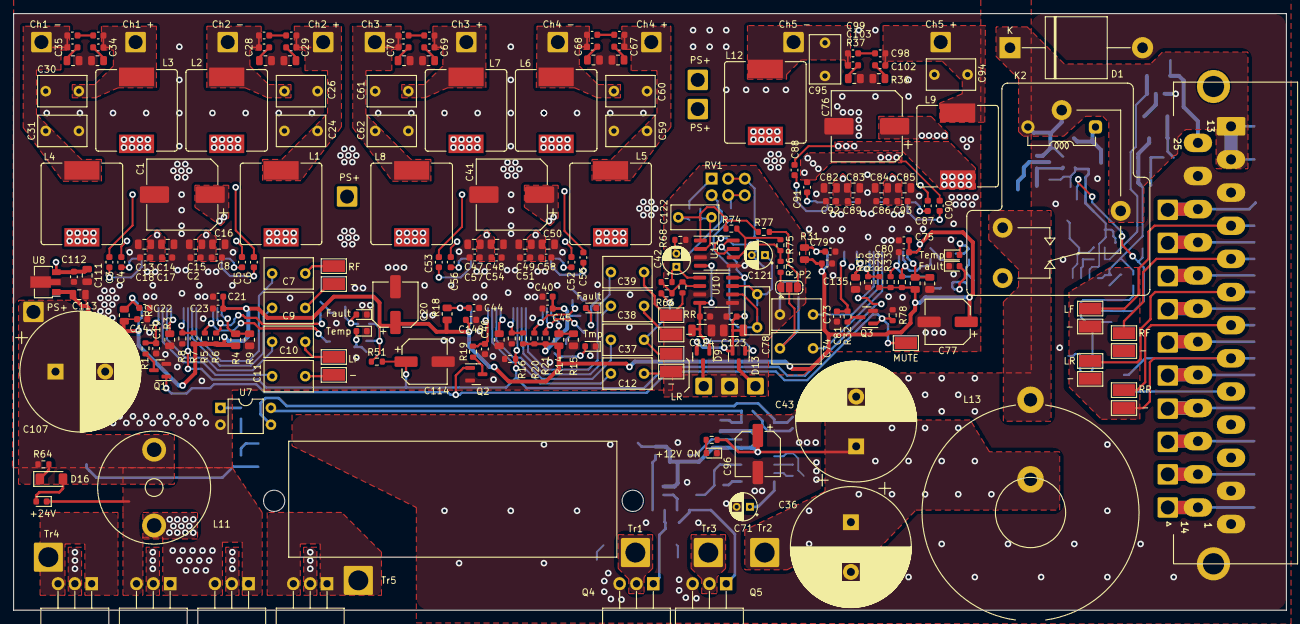
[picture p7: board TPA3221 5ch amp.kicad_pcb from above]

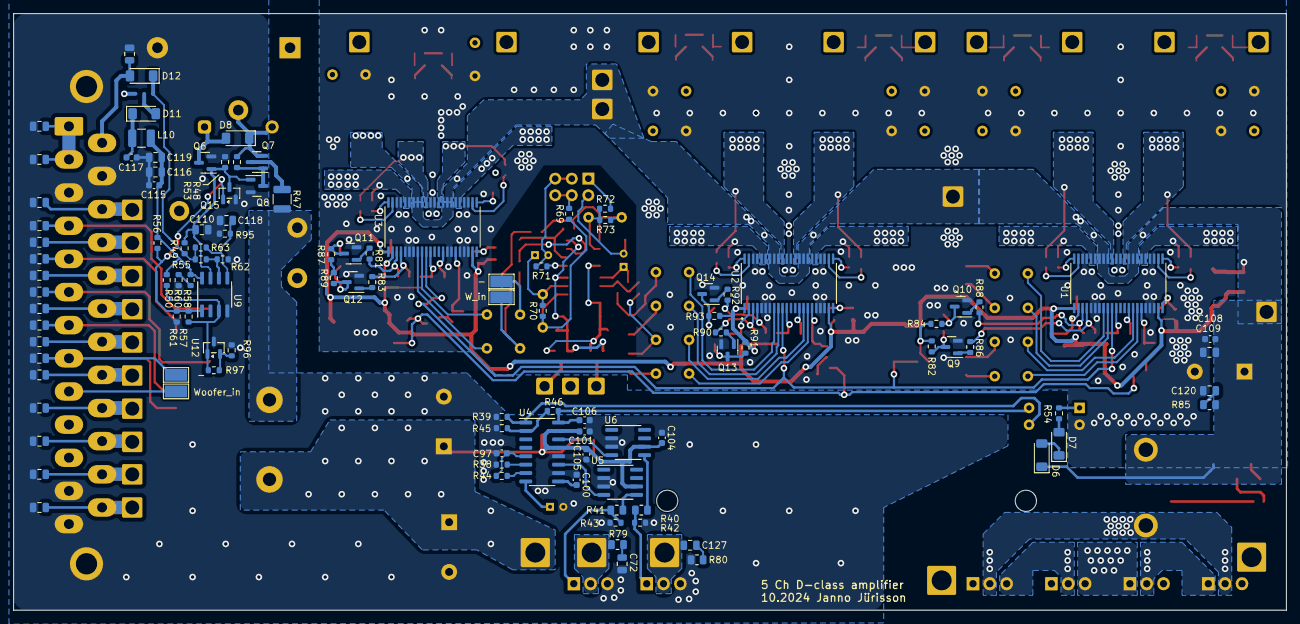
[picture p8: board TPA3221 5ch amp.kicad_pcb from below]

Board: 2 copper layers, 192.0 x 90.0 mm, 364 parts (109 on the bottom side), 168 nets.
